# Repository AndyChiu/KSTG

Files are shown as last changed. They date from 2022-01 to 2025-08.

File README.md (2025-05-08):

# KSTG
鍵帽存放托盤產生器(Keycap Storage Tray Generator)
Version: 2025/5/8

此產生器使用OpenSCAD來打造存放鍵帽的托盤，可以有效運用廢棄盒子，依盒子尺寸與鍵帽尺寸來建立最合適的托盤，讓空間有效運用，並減少廢棄物。\
This generator uses OpenSCAD to design trays for storing keycaps. It allows you to reuse discarded boxes efficiently by creating a tray that fits both the box and keycap dimensions, optimizing space usage and reducing waste.

範例：分隔版樣式\
Examples: Separator Styles

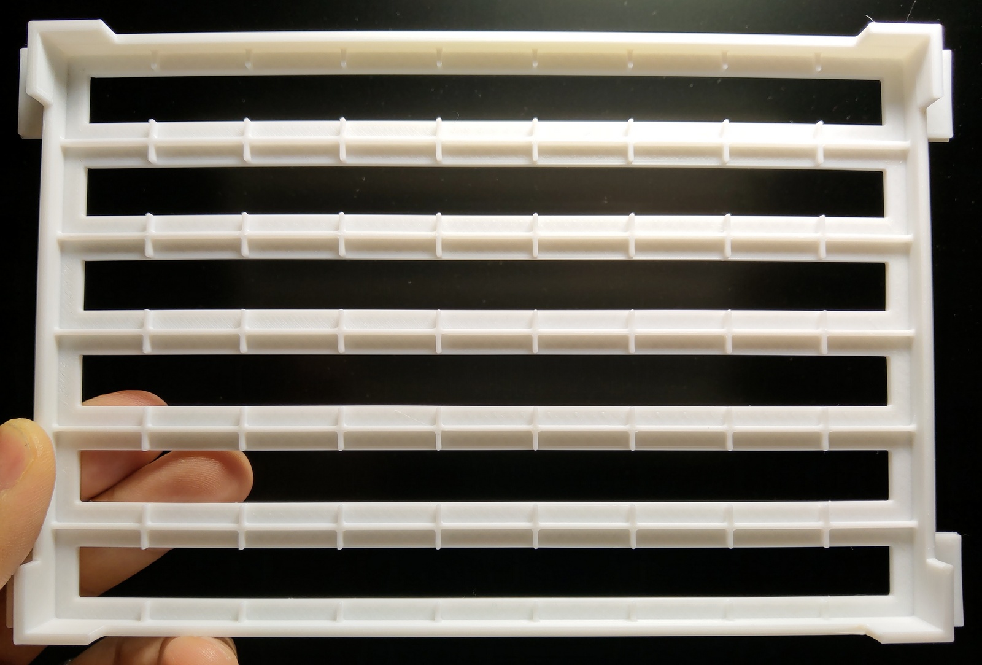
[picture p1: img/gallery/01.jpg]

垂直分隔片樣式：2-短隔板無底板\
Vertical separator style: 2 - Short dividers without base

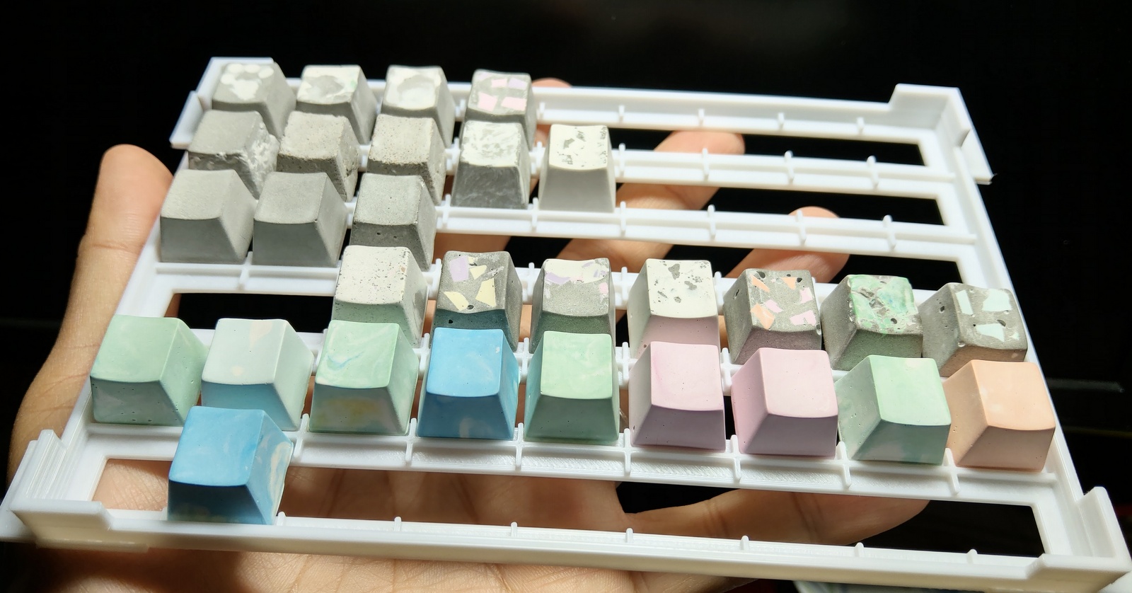
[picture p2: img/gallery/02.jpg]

垂直分隔片樣式：2-短隔板無底板\
Vertical separator style: 2 - Short dividers without base

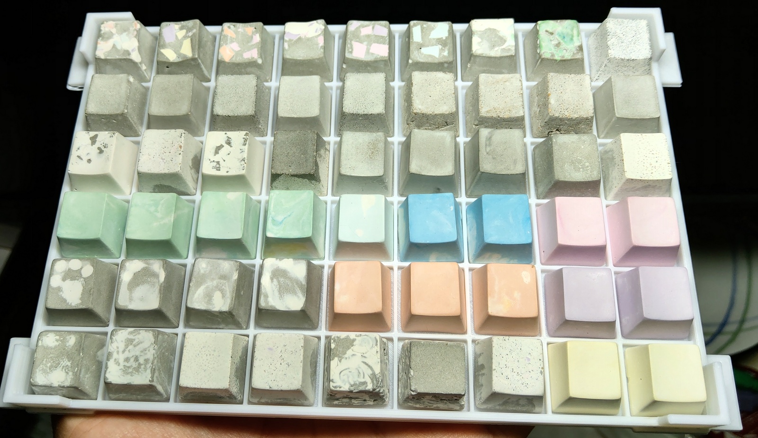
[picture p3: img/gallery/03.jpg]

垂直分隔片樣式：1-全部\
Vertical separator style: 1 - Full

範例：放入盒內\
Examples: Inside the Box

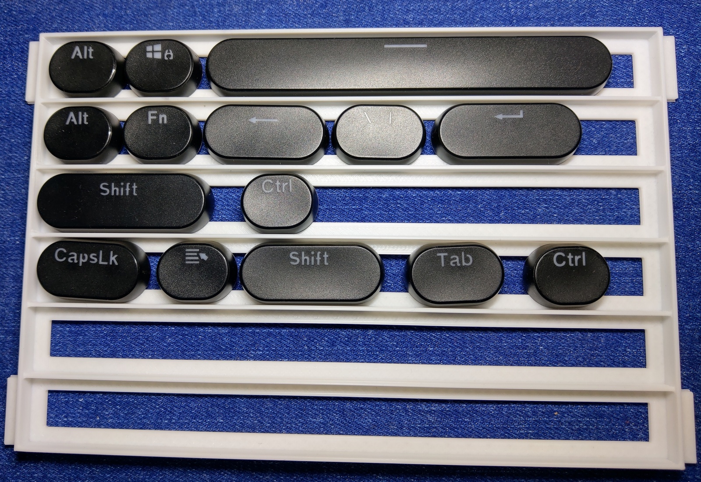
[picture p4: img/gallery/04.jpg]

垂直分隔片樣式：0-不需要\
Vertical separator style: 0 - Not needed

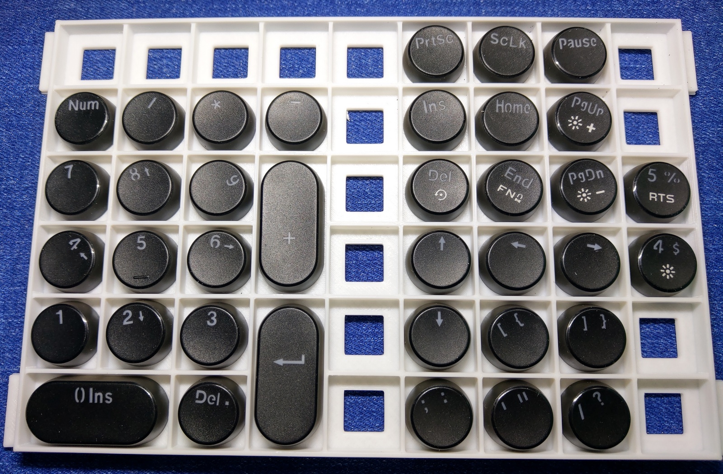
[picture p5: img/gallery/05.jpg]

垂直分隔片樣式：1-全部\
Vertical separator style: 1 - Full\
搭配手動清除分隔片與底板\
Used with manually removed separators and base plates

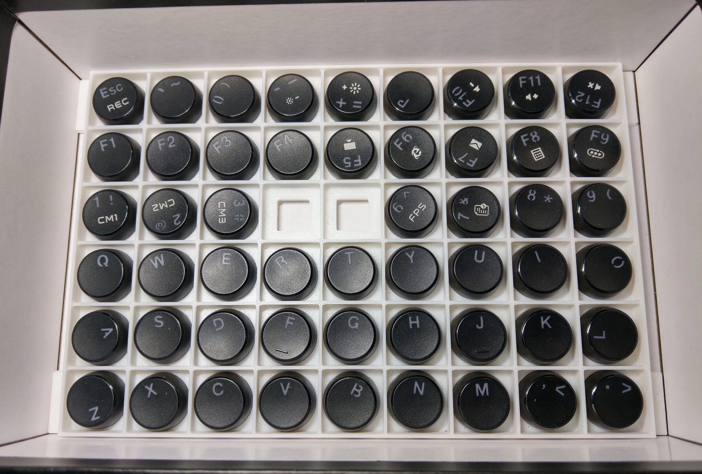
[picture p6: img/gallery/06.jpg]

放置時可預留空間，比較好拿取托盤\
Leave some space when placing to make trays easier to retrieve

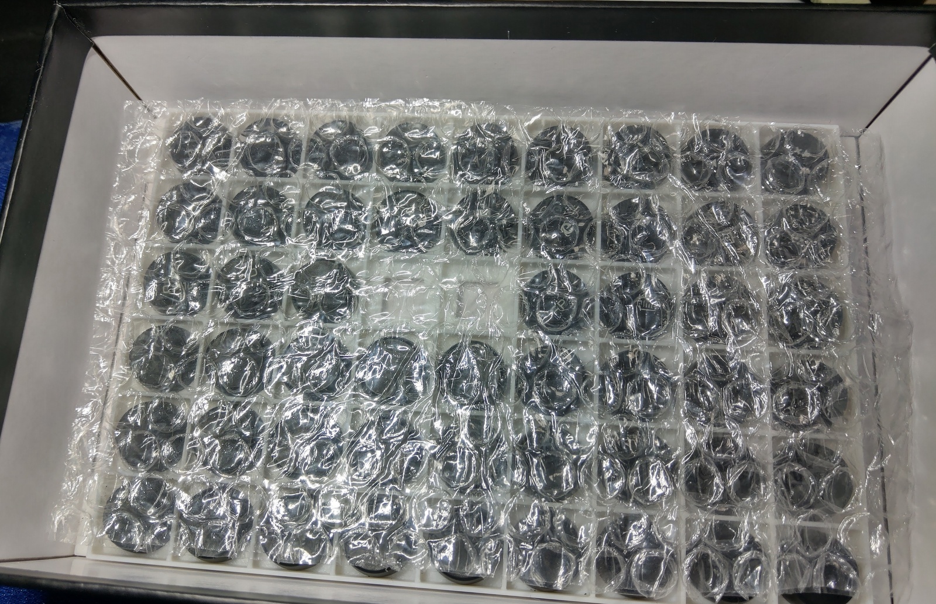
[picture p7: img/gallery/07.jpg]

裁切同等大小的泡綿\
Cut foam sheets to matching size

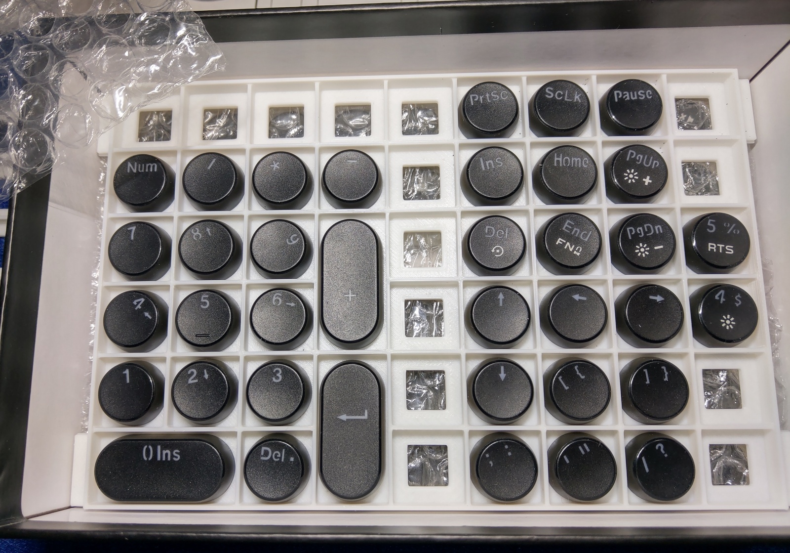
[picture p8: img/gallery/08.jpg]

再放上另一層\
Add another layer on top

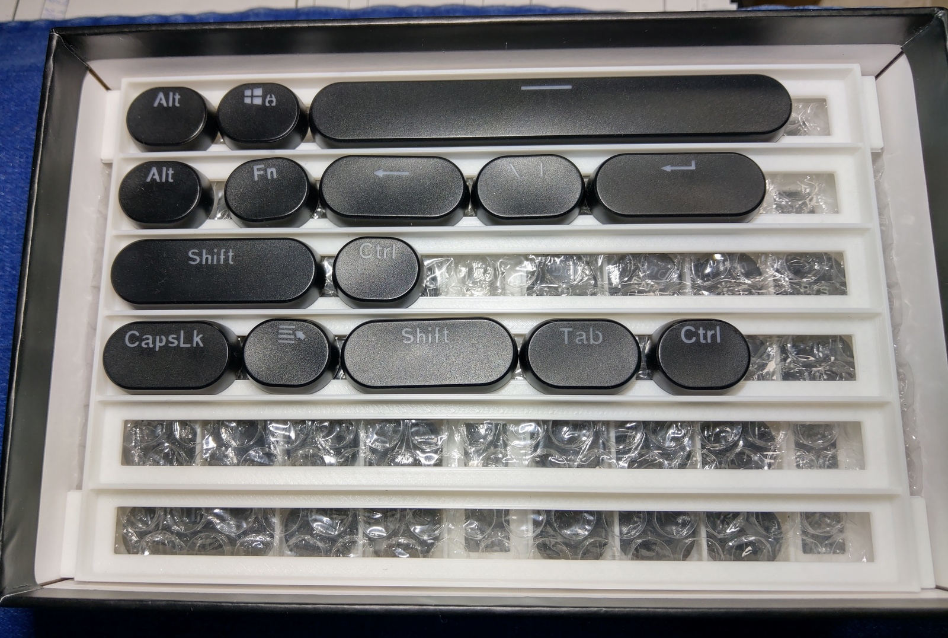
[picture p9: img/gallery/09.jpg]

放入第三層，如果空間沒有滿，可塞填充物，避免攜帶時鍵帽脫離位置\
Insert a third layer. If there’s extra space, fill with cushioning material to prevent keycaps from shifting during transport

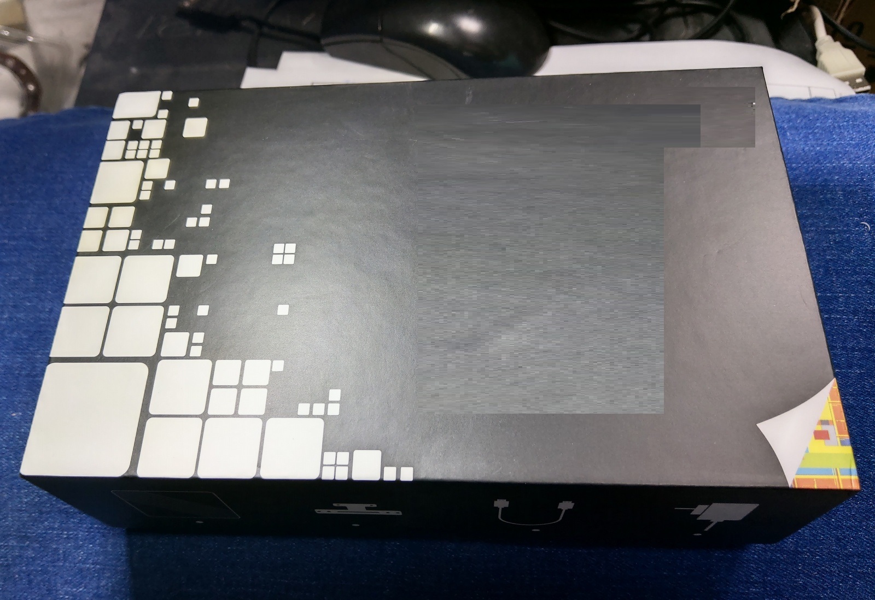
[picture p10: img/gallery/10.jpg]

蓋上盒蓋，完成收納\
Close the lid — storage complete

範例：使用B5文件夾\
Example: Using a B5 Document Folder

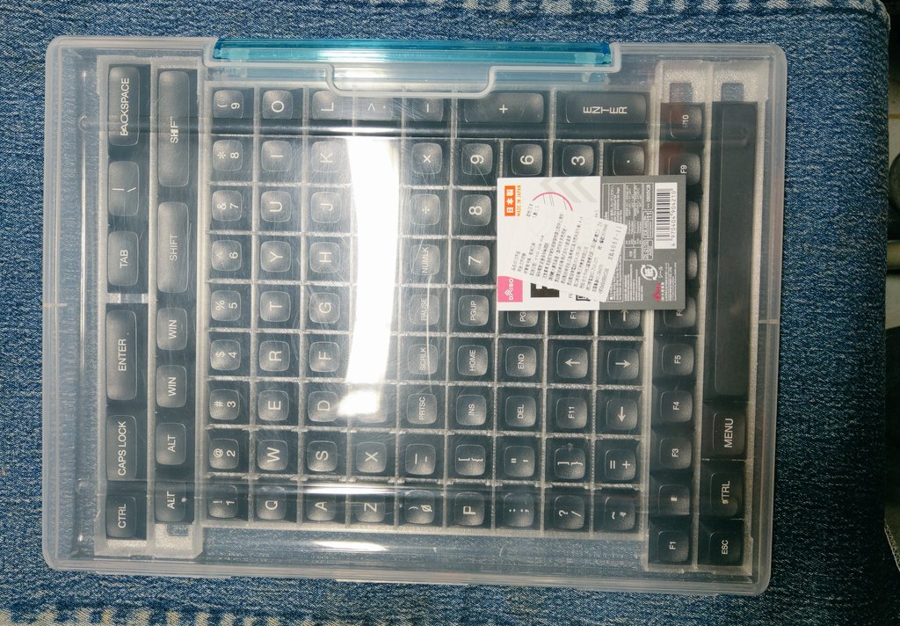
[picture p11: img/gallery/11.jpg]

B5文件夾\
B5 Document Folder

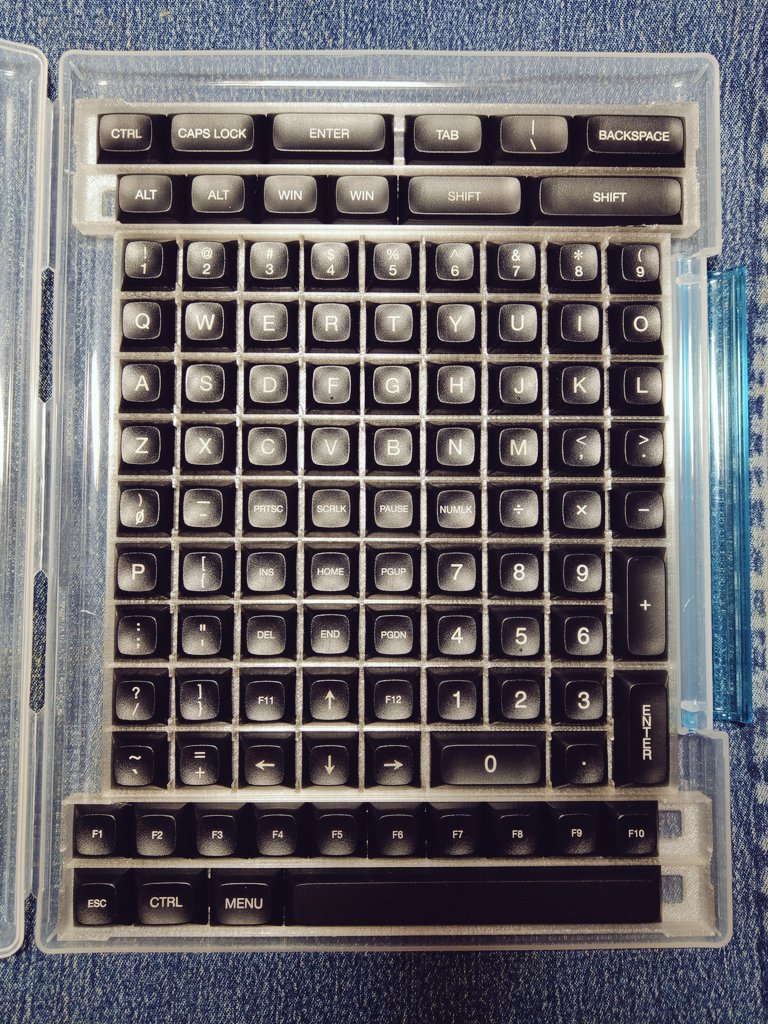
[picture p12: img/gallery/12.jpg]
\
可完整放入104鍵鍵帽\
Fits all 104 keycaps perfectly

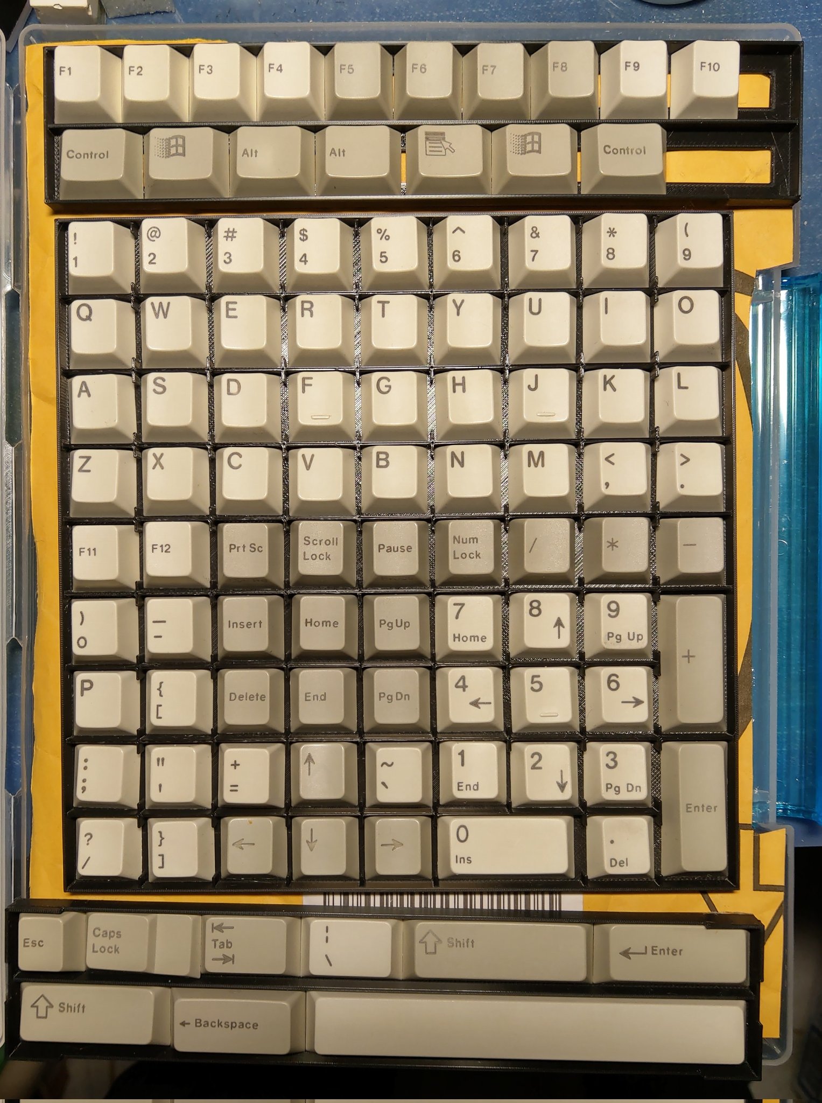
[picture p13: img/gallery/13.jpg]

第二層\
Second layer

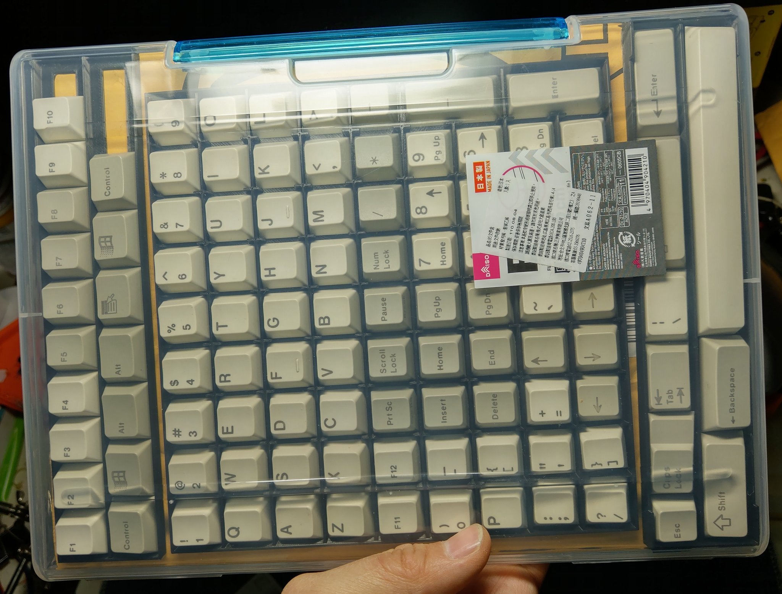
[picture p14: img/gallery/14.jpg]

兩層鍵帽組合起來高度剛好\
The height of two keycap layers fits just right

新增項目:\
New Features:

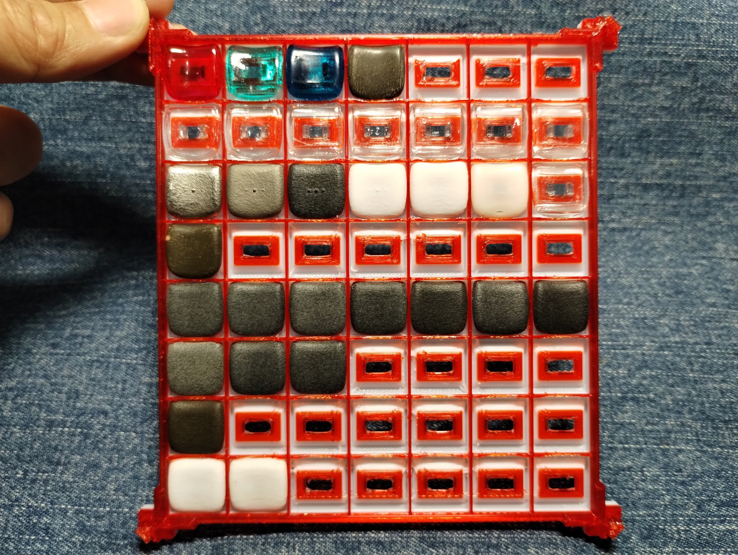
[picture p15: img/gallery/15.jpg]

Choc V1用的Stem插孔\
Stem socket for Choc V1

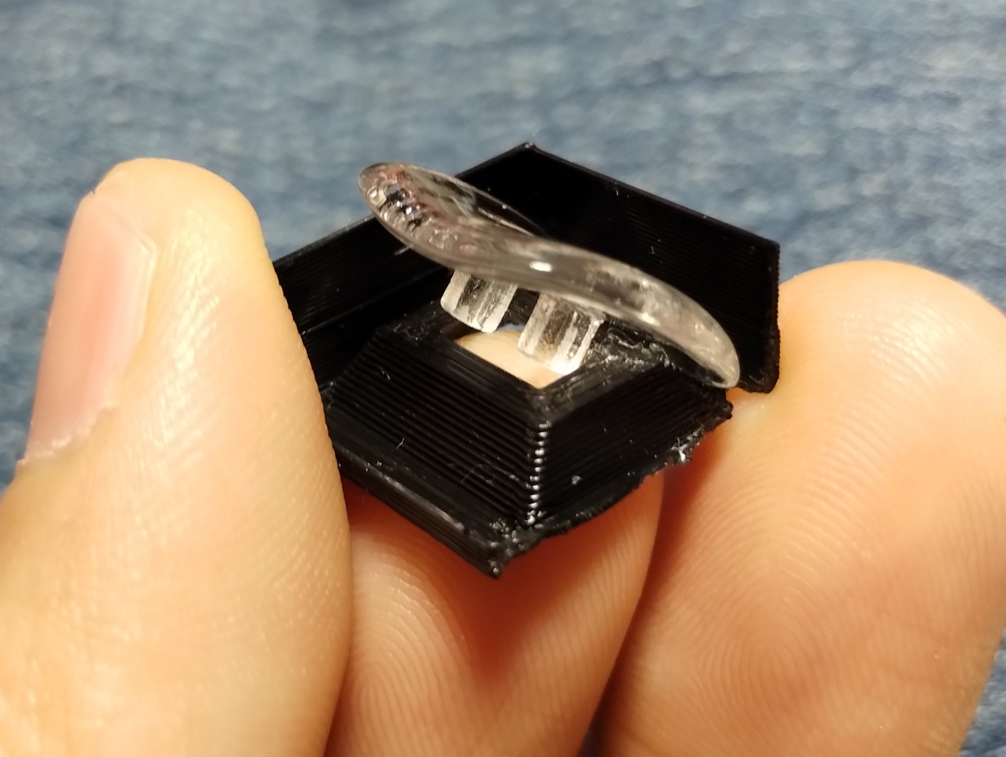
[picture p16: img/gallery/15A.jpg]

背後有往上凸，可用手指將鍵帽推出來。\
Raised backing allows keycaps to be pushed out with a finger.

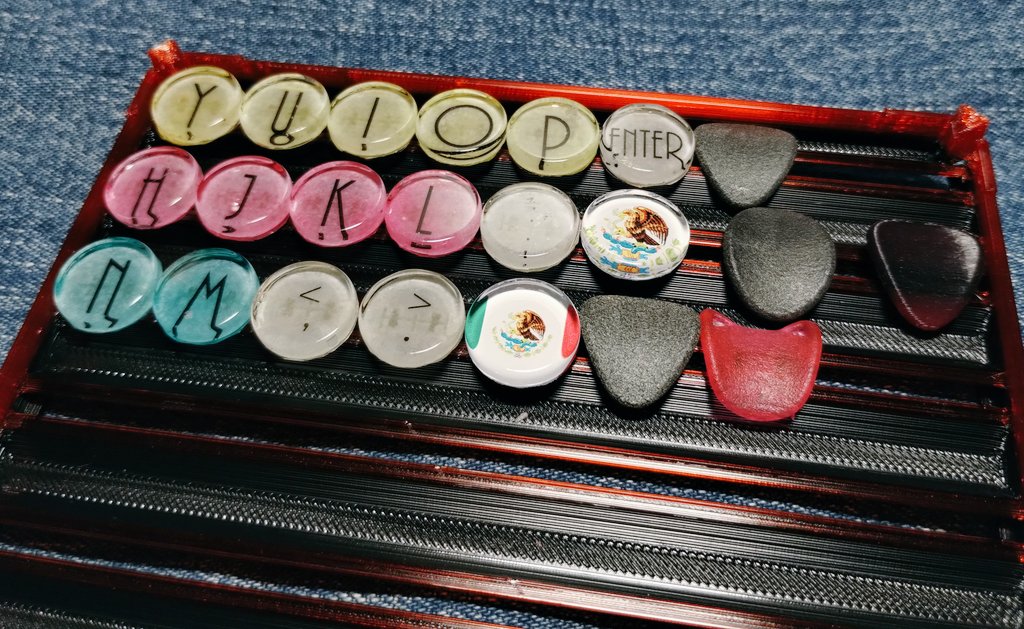
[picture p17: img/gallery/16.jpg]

Choc V1用的Stem插孔，一長排的開孔，用於無裙鍵帽，可減少部分使用空間。\
Choc V1 stem socket – a long slot designed for skirtless keycaps, saves some space.

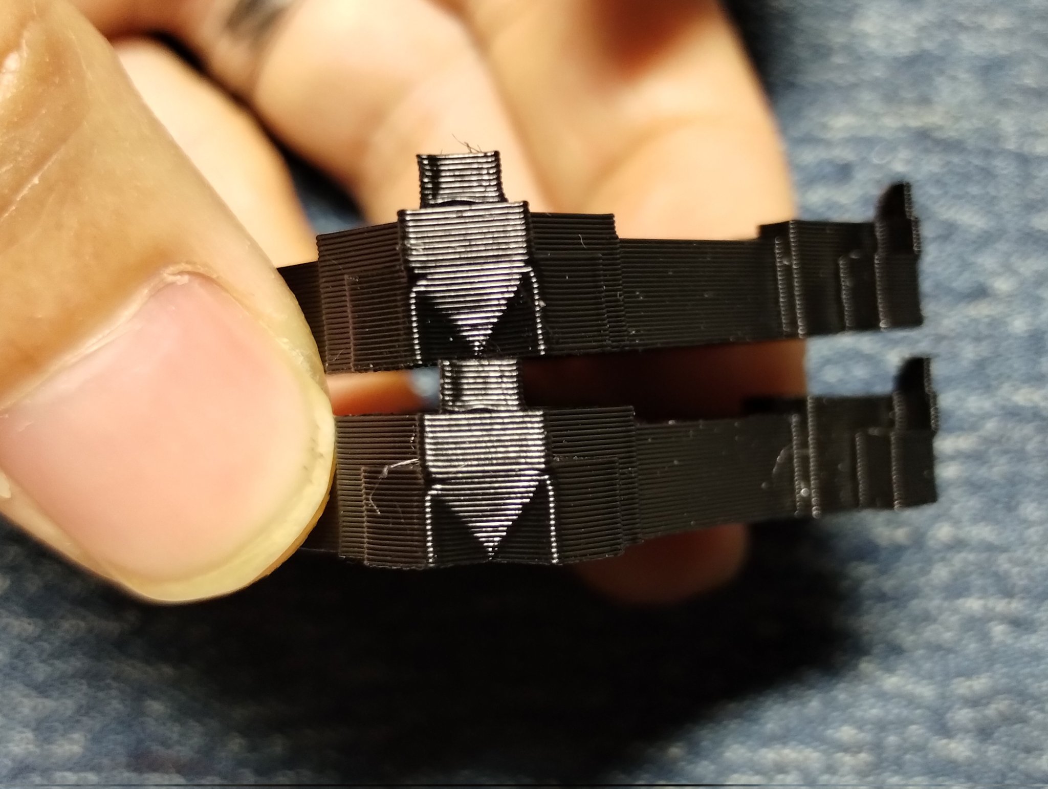
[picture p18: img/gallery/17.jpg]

托盤固定槽榫，多盤時，可以對準堆疊托盤。\
Tray alignment notches – help align and stack multiple trays.

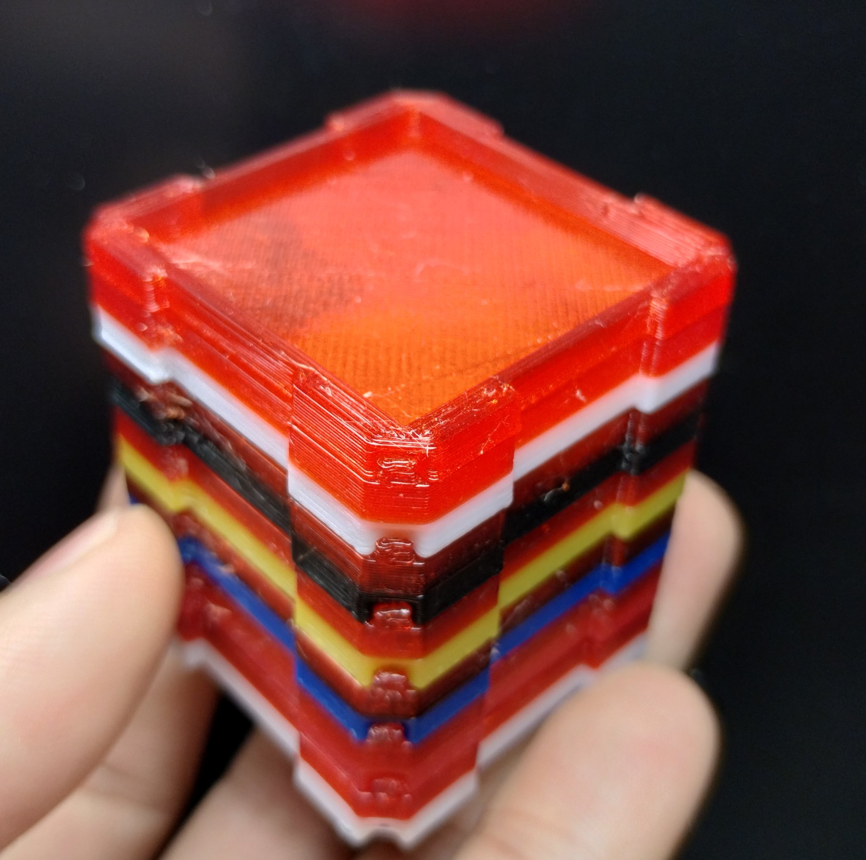
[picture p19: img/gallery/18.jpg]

多盤堆疊範例，可透過固定槽榫固定多個托盤，可由 CreateKST_Cover() 建立上蓋，如果不放盒子內，僅印出堆疊，可以用盒子蓋住，較為完整。\
Example of stacking multiple trays: alignment notches allow trays to be securely stacked. A top cover can be created using CreateKST_Cover(). If not placing the trays inside a box, simply printing and covering the stack with a lid provides a more complete solution.

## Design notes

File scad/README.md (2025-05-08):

# 主程式 Main Program
請複製一份 KSTG_Template.scad 檔案，並依照自己的情況修改參數，再自行改成所需的檔案名稱即可
此檔案會載入 KSTG_Base.SCAD，只要這個檔案不改檔名，能夠被載入就沒太大的問題

Make a copy of the KSTG_Template.scad file, modify the parameters to suit your needs, and rename it as desired.
This file will load KSTG_Base.SCAD; as long as the filename remains unchanged and it can be found, everything should work fine.

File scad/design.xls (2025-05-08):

 |  |  | // 分隔片
 |  |  | Tray_Separator_L = 3; //短隔板長度
 |  |  | // 分隔片(長寬區分)
 |  |  | Tray_Separator_H_L = 4; //高度(長;水平)
 |  |  | Tray_Separator_T_L = 1; //厚度(長;水平)
 |  |  | Tray_Separator_H_W = 4; //高度(寬;垂直)
 |  |  | Tray_Separator_T_W = 2; //厚度(寬;垂直)
 |  |  | //四角落立柱高度
 |  |  | //堆疊托盤時可墊高避免直接碰觸鍵帽
 |  |  | Tray_Column_H = 10; // 高度 可依照鍵帽高度調整
 |  |  | Tray_Column_T = 2; // 厚度
 |  | //填補空間高度 | Tray_Column_W = 15; // 寬面長度
// 外圍厚度 | Tray_Column_L = 15; | ES_H = 3;
Tray_Fence_T = 1; //厚度 | // 長面長度
Tray_Fence_H = 4; //高度 |  | //延伸長度
 |  | ES_WE = 10;
 |  | ES_LE = 10;
 |  |  | // 底板
 | //放置鍵帽空間 |  | // 如果給Stem突出的鍵帽,計算出的"中央開口"孔徑要大於特定尺寸才能正常插入,厚度值則要足夠才不會接觸到下層鍵帽,例如iRock矮鍵帽需5.5mm厚度3.5mm、Kailh Choc矮軸鍵帽需7mm厚度2mm,如開口不夠大請調整 Tray_Bottom_L 參數
 | Keycaps_Space_L = 20.6; |  | Tray_Bottom_L = (Keycaps_Space_W-9)/2; //水平底板寬度
 | Keycaps_Space_W = 16.6; |  | Tray_Bottom_W = (Keycaps_Space_L-14)/2; //垂直底板寬度
 |  |  | Tray_Bottom_T = 2; //底板厚度
 |  |  | Tray_Corner_FST_HA = 0; // 高度增減，可依需求調整 // Height adjustment – customize as needed
 |  |  | Tray_Corner_FST_D = 45; // 斜切角度 // Chamfer angle
 |  |  | Tray_Corner_FST_L = 5; // 長面長度 // Long side length
 |  |  | Tray_Corner_FST_W = 5; // 寬面長度，長寬建議相同 // Wide side length (suggest keeping width = length)
 |  |  | Tray_Corner_FST_S = 0.4; // 榫縮尺寸 // Tenon shrink offset
 |  |  | Tray_Corner_FST_TH = 3; // 榫頭高度 // Tenon head height
 |  |  | // 存放盒子的大小:
 |  |  | BoxSize_L1 = 137; //Length 長度(水平;x軸) row
 |  |  | BoxSize_W1 = 147; //Width 寬度(垂直;y軸) col
 |  |  | BoxSize_H1 = 49.5; //Height 高度
 |  |  | //水平分隔片 行數 (長;水平)
 |  |  | //=((外盒寬度 - (外圍厚度*2) + 邊緣分隔板厚度 )
 |  |  | // /(放置鍵帽空間W+分隔片L厚度))
 |  |  | Tray_HS_Q = floor((BoxSize_W1-(Tray_Fence_T*2)+Edge_Separator_L_T)/(Keycaps_Space_W+Tray_Separator_T_L));

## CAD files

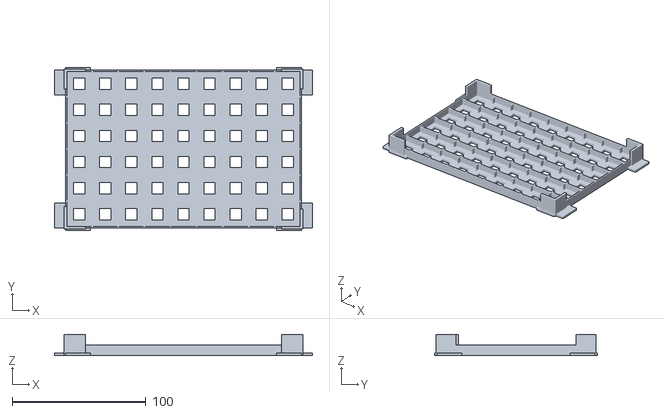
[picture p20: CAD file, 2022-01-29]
stl_Sample/KSTG_Sample5.stl
193.0 x 122.0 x 16.0

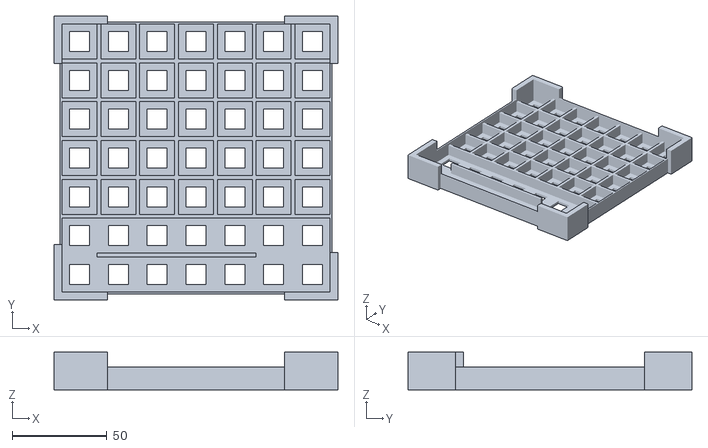
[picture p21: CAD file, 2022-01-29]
stl_Sample/KSTG_Sample7.stl
150.0 x 150.0 x 20.0

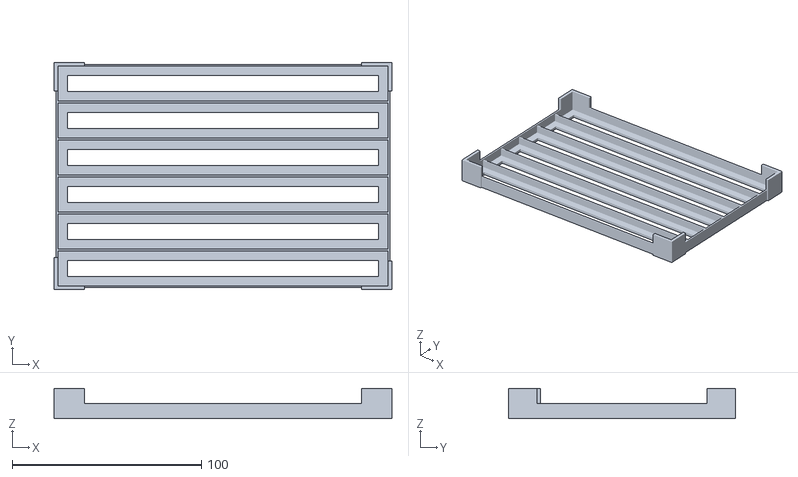
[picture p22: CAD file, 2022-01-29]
stl_Sample/KSTG_Sample4.stl
178.5 x 120.0 x 16.0

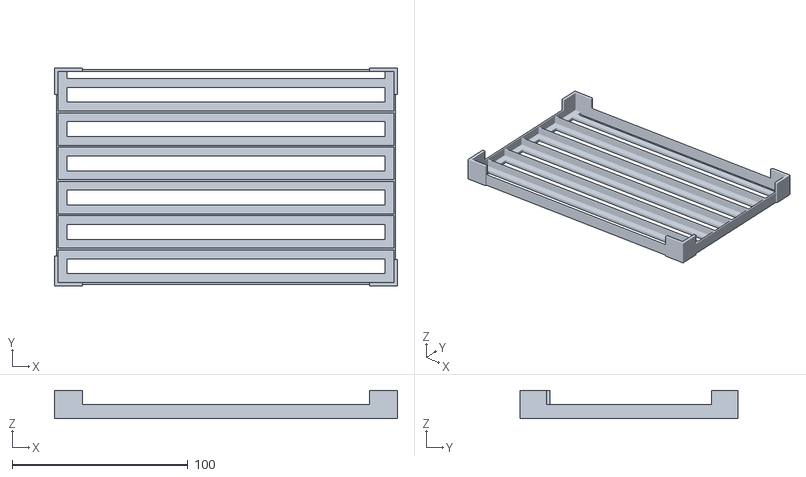
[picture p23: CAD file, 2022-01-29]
stl_Sample/KSTG_Sample3.stl
195.0 x 124.0 x 16.0

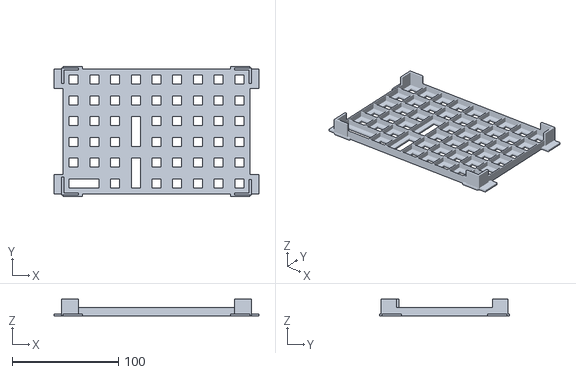
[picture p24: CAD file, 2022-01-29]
stl_Sample/KSTG_Sample1.stl
193.0 x 122.0 x 16.0

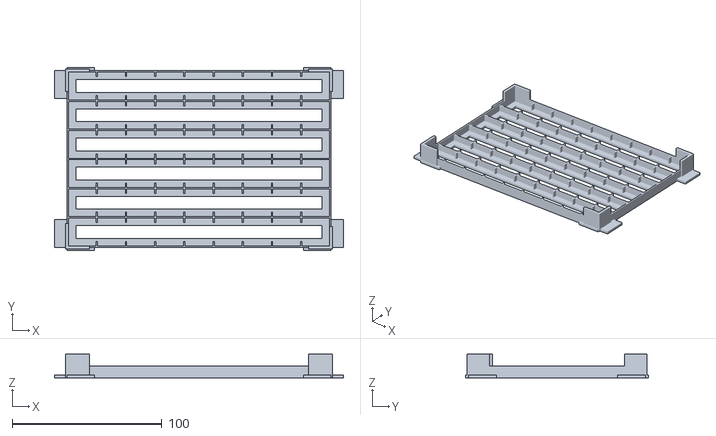
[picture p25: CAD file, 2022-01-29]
stl_Sample/KSTG_Sample6.stl
193.0 x 122.0 x 16.0

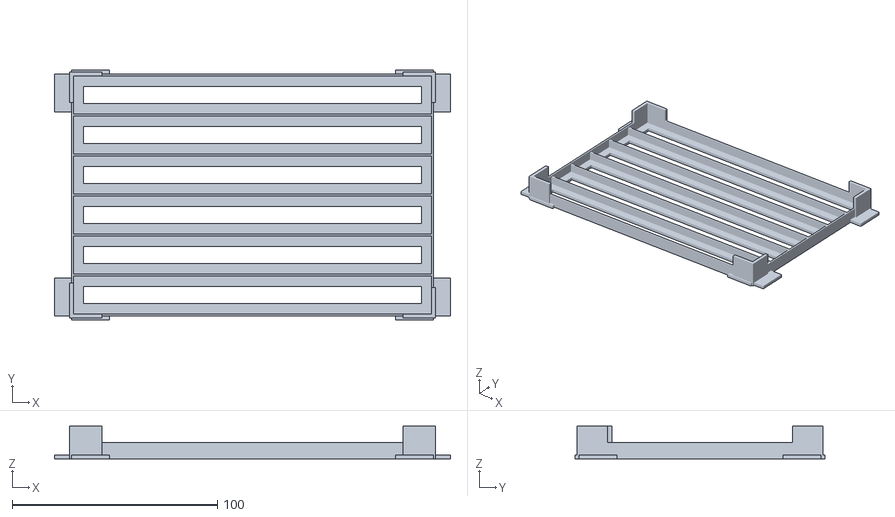
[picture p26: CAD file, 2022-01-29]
stl_Sample/KSTG_Sample2.stl
193.0 x 122.0 x 16.0

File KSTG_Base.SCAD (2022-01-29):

// Keycaps 存放架產生器
// keycap storage tray generator

module CreateBase() 
{
//邊緣分隔板厚度(最小值)
Edge_Separator_L_T = Tray_Fence_T > Tray_Separator_T ?  Tray_Separator_T : Tray_Fence_T ;
Edge_Separator_W_T= Tray_Fence_T > Tray_Separator_T ? Tray_Fence_T : Tray_Separator_T ;
    
//水平分隔片 行數 長度(水平)
Tray_HS_Q = floor((BoxSize_W1-(Tray_Fence_T*2)+Edge_Separator_L_T)/(Keycaps_Space_W+Tray_Separator_T));

//垂直分隔片 列數 寬度(垂直)
Tray_VS_Q = floor((BoxSize_L1-(Tray_Fence_T*2)+Edge_Separator_W_T)/(Keycaps_Space_L+Tray_Separator_T));

//盒子可放幾個托盤
Tray_Q = floor(BoxSize_H/(Tray_Column_H+Tray_Bottom_T));

echo(str("存放盒子長寬高：", BoxSize_L1,"mm x ",BoxSize_W1,"mm x ",BoxSize_H, "mm"));

echo(str("托盤分隔 行x列 數：", Tray_HS_Q,"行 x ",Tray_VS_Q,"列"));

//可使用總U數
echo(str("單一托盤可裝：", Tray_HS_Q*Tray_VS_Q, "U"));
echo(str("單盒可存盤數：", Tray_Q, ""));
echo(str("單盒可存鍵帽：", Tray_HS_Q*Tray_VS_Q*Tray_Q, "U"));

// 修正後存放盒子的大小:
BoxSize_L2 = Tray_VS_Q*(Keycaps_Space_L+Tray_Separator_T)+(Tray_Fence_T*2)-Tray_Separator_T; //長度
BoxSize_W2 = Tray_HS_Q*(Keycaps_Space_W+Tray_Separator_T)+(Tray_Fence_T*2)-Tray_Separator_T; //寬度
echo("使用空間L2=", BoxSize_L2, "");
echo("使用空間W2=", BoxSize_W2, "");

//多出來的邊界空間
ES_L2=BoxSize_L1-BoxSize_L2;
ES_W2=BoxSize_W1-BoxSize_W2;

ES_L=ES_L2/2;
ES_W=ES_W2/2;

echo("多餘空間L=", ES_L2, "");
echo("多餘空間W=", ES_W2, "");

echo("中央開口",Keycaps_Space_L-(Tray_Bottom_L*2)," x ",Keycaps_Space_W-(Tray_Bottom_L*2));

BoxSize_L = ExtraSpaceUse==0 ? BoxSize_L1 : BoxSize_L2;
BoxSize_W = ExtraSpaceUse==0 ? BoxSize_W1 : BoxSize_W2;

//繪製四面牆
cube([BoxSize_L,Tray_Fence_T,Tray_Fence_H+Tray_Bottom_T],false); //長 水平
cube([Tray_Fence_T,BoxSize_W,Tray_Fence_H+Tray_Bottom_T],false); //寬 垂直
translate([0,BoxSize_W-Tray_Fence_T,0]) 
    cube([BoxSize_L,Tray_Fence_T,Tray_Fence_H+Tray_Bottom_T],false);
translate([BoxSize_L-Tray_Fence_T,0,0]) 
    cube([Tray_Fence_T,BoxSize_W,Tray_Fence_H+Tray_Bottom_T],false);
//長 水平 底板    
//translate([0,Tray_Fence_T,0]) 
//    cube([BoxSize_L,Tray_Bottom_L+Tray_Separator_T/2,Tray_Bottom_T],false);
//translate([0,BoxSize_W-Tray_Fence_T-Tray_Bottom_L,0]) 
//    cube([BoxSize_L,Tray_Bottom_L,Tray_Bottom_T],false);
    
//寬 垂直 底板    
translate([0,0,0]) 
    cube([Tray_Fence_T+Tray_Bottom_L,BoxSize_W,Tray_Bottom_T],false);
translate([BoxSize_L-(Tray_Fence_T+Tray_Bottom_L),0,0]) 
    cube([Tray_Fence_T+Tray_Bottom_L,BoxSize_W,Tray_Bottom_T],false);

//水平搭橋 四面牆不處理   

//底板
for (i =[1:Tray_HS_Q])
translate([0,(Keycaps_Space_L+Tray_Separator_T)*i-Tray_Bottom_L+Tray_Fence_T-Tray_Separator_T,0]) 
    cube([BoxSize_L,Tray_Bottom_L,Tray_Bottom_T],false);

for (i =[1:Tray_HS_Q])
translate([0,(Keycaps_Space_L+Tray_Separator_T)*(i-1)+Tray_Fence_T,0]) 
    cube([BoxSize_L,Tray_Bottom_L,Tray_Bottom_T],false);

//水平分隔片 
//abs(Tray_Fence_T-Tray_Separator_T)
for (i =[1:Tray_HS_Q-1])
translate([0,(Keycaps_Space_L+Tray_Separator_T)*i+Tray_Fence_T-Tray_Separator_T,0]) 
    cube([BoxSize_L,Tray_Separator_T,Tray_Separator_H+Tray_Bottom_T],false);
    
//垂直搭橋

// 0 不使用
//if(Tray_VS_Type==0);

// 1、3 底板
if(Tray_VS_Type==1 || Tray_VS_Type==3) {
    //右
    for (i =[1:Tray_VS_Q])
    translate([(Keycaps_Space_W+Tray_Separator_T)*i-Tray_Bottom_L-Tray_Separator_T+Tray_Fence_T,0,0]) 
        cube([Tray_Bottom_L,BoxSize_W,Tray_Bottom_T],false);
    //左
    for (i =[1:Tray_VS_Q-1])
    translate([(Keycaps_Space_W+Tray_Separator_T)*i+Tray_Fence_T,0,0]) 
        cube([Tray_Bottom_L,BoxSize_W,Tray_Bottom_T],false);
    //中
    for (i =[1:Tray_VS_Q-1])
    translate([(Keycaps_Space_W+Tray_Separator_T)*i-Tray_Separator_T+Tray_Fence_T,0,0])  
        cube([Tray_Separator_T,BoxSize_W,Tray_Bottom_T],false);
    }

// 垂直分隔片  
// 2、3 短隔板
if(Tray_VS_Type==2 || Tray_VS_Type==3) {
      
    //上
    for (i =[1:Tray_VS_Q-1])
        for (j =[1:Tray_HS_Q])
    translate([(Keycaps_Space_W+Tray_Separator_T)*i+Tray_Fence_T-Tray_Separator_T,(Keycaps_Space_L+Tray_Separator_T)*j-Tray_Separator_L+Tray_Fence_T-Tray_Separator_T,0]) 
        cube([Tray_Separator_T,Tray_Separator_L,Tray_Separator_H+Tray_Bottom_T],false);
    //下
    for (i =[1:Tray_VS_Q-1])
        for (j =[1:Tray_HS_Q])
    translate([(Keycaps_Space_W+Tray_Separator_T)*i+Tray_Fence_T-Tray_Separator_T,(Keycaps_Space_L+Tray_Separator_T)*(j-1)+Tray_Fence_T,0]) 
        cube([Tray_Separator_T,Tray_Separator_L,Tray_Separator_H+Tray_Bottom_T],false);

    }
// 2 全部
else if(Tray_VS_Type==1) {
    //垂直分隔片    
    for (i =[1:Tray_VS_Q-1])
    translate([(Keycaps_Space_W+Tray_Separator_T)*i+Tray_Fence_T-Tray_Separator_T,0,0]) 
        cube([Tray_Separator_T,BoxSize_W,Tray_Separator_H+Tray_Bottom_T],false);
    
    }
 
//多餘空間處理方式
// 2 角落填補剩餘空間
 if (ExtraSpaceUse == 2) {
    //左下下
    translate([0,-ES_W,0]) 
        cube([Keycaps_Space_W,ES_W,Tray_Bottom_T],false);
    //左下左
     translate([-ES_L,0,0]) 
        cube([ES_L,Keycaps_Space_L,Tray_Bottom_T],false);    

     //左上左
     translate([-ES_L,BoxSize_W-Keycaps_Space_L,0]) 
        cube([ES_L,Keycaps_Space_L,Tray_Bottom_T],false); 
     //左上上
     translate([0,BoxSize_W,0]) 
        cube([Keycaps_Space_W,ES_W,Tray_Bottom_T],false);
     //右下右
     translate([BoxSize_L,0,0]) 
        cube([ES_L,Keycaps_Space_L,Tray_Bottom_T],false);    
     //右下下
     translate([BoxSize_L-Keycaps_Space_W,-ES_W,0]) 
        cube([Keycaps_Space_W,ES_W,Tray_Bottom_T],false);
     //右上右
     translate([BoxSize_L,BoxSize_W-Keycaps_Space_L,0]) 
        cube([ES_L,Keycaps_Space_L,Tray_Bottom_T],false);    
     //右上上
     translate([BoxSize_L-Keycaps_Space_W,BoxSize_W,0]) 
        cube([Keycaps_Space_W,ES_W,Tray_Bottom_T],false);
        
    }
     
// 四角落立柱
  
Tray_Column_T_L = Tray_Column_T > Tray_Fence_T + ES_L ?  Tray_Fence_T + ES_L : Tray_Column_T ;

Tray_Column_T_W = Tray_Column_T > Tray_Fence_T + ES_W ?  Tray_Fence_T + ES_W : Tray_Column_T ;

// 左下下
translate([0,Tray_Fence_T-Tray_Column_T_W,0]) 
    cube([Tray_Column_L,Tray_Column_T_W,Tray_Column_H+Tray_Bottom_T],false);  
// 左下左
translate([Tray_Fence_T-Tray_Column_T_L,Tray_Fence_T-Tray_Column_T_W,0]) 
    cube([Tray_Column_T_L,Tray_Column_L+Tray_Column_T_L,Tray_Column_H+Tray_Bottom_T],false);   
// 右下下
translate([BoxSize_L-Tray_Column_L,Tray_Fence_T-Tray_Column_T_W,0]) 
    cube([Tray_Column_L,Tray_Column_T_W,Tray_Column_H+Tray_Bottom_T],false);
// 右下右
translate([BoxSize_L-Tray_Column_T_L-Tray_Fence_T+Tray_Column_T_W,Tray_Fence_T-Tray_Column_T_L,0]) 
    cube([Tray_Column_T_L,Tray_Column_W,Tray_Column_H+Tray_Bottom_T],false); 
// 左上上     
translate([0,BoxSize_W-Tray_Column_T_W-Tray_Fence_T+Tray_Column_T_W,0]) 
    cube([Tray_Column_L,Tray_Column_T_W,Tray_Column_H+Tray_Bottom_T],false);
// 左上左   
translate([Tray_Fence_T-Tray_Column_T_L,BoxSize_W-Tray_Column_W-Tray_Fence_T+Tray_Column_T_W,0])
    cube([Tray_Column_T_L,Tray_Column_W,Tray_Column_H+Tray_Bottom_T],false); 
//右上上
translate([BoxSize_L-Tray_Column_L,BoxSize_W-Tray_Column_T_W-Tray_Fence_T+Tray_Column_T_W,0]) 
    cube([Tray_Column_L,Tray_Column_T_W,Tray_Column_H+Tray_Bottom_T],false);
//右上右   
translate([BoxSize_L-Tray_Column_T_L-Tray_Fence_T+Tray_Column_T_L,BoxSize_W-Tray_Column_W-Tray_Fence_T+Tray_Column_T_W,0])
    cube([Tray_Column_T_L,Tray_Column_W,Tray_Column_H+Tray_Bottom_T],false); 

//文字標記
if (ShowText==1) { 
    
for (i =[1:Tray_VS_Q])
    for (j =[1:Tray_HS_Q-1])
    translate([(Keycaps_Space_W+Tray_Separator_T)*i+Tray_Fence_T-Tray_Separator_T-Keycaps_Space_W/1.5,(Keycaps_Space_L+Tray_Separator_T)*j-Tray_Bottom_L+Tray_Fence_T-Tray_Separator_T+3,Tray_Bottom_T+Tray_Separator_H+1]) 
        color( "Red", 0.3 )text(str(i,",",j),3);

for (i =[1:Tray_VS_Q-1])
    for (j =[1:Tray_HS_Q])
    translate([(Keycaps_Space_W+Tray_Separator_T)*i+Tray_Fence_T-Tray_Separator_T-Keycaps_Space_W/4+3,(Keycaps_Space_L+Tray_Separator_T)*j-Tray_Bottom_L+Tray_Fence_T-Tray_Separator_T-Keycaps_Space_L/2+3,Tray_Bottom_T+Tray_Separator_H+1]) 
        color( "Navy", 0.3 )text(str(i,",",j),3);

for (i =[1:Tray_VS_Q-1])
    for (j =[1:Tray_HS_Q-1])
    translate([(Keycaps_Space_W+Tray_Separator_T)*i+Tray_Fence_T-Tray_Separator_T-Keycaps_Space_W/4+3,(Keycaps_Space_L+Tray_Separator_T)*j-Tray_Bottom_L+Tray_Fence_T-Tray_Separator_T+3,Tray_Bottom_T+Tray_Separator_H+1]) 
        color( "Lime", 0.3 )text(str(i,",",j),3);
    
};

}
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

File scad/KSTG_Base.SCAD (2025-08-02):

/*
====================================
  鍵帽存放托盤產生器(KSTG)
  Keycap Storage Tray Generator
====================================
使用 include <KSTG_Base.SCAD> 加載此檔案
Use include <KSTG_Base.SCAD> to load this file

建立鍵帽存放托盤
Create Keycap Storage Tray
CreateKST();

建立鍵帽存放托盤上蓋
Create Keycap Storage Tray Cover
CreateKST_Cover();

KSTG_Template.scad 有詳細設定說明
KSTG_Template.scad contains detailed configuration instructions
*/

module CreateBase() 
{
//邊緣分隔板厚度(分隔片厚度 與 外圍厚度 取最小值)
Edge_Separator_L_T = Tray_Fence_T > Tray_Separator_T_L ?  Tray_Separator_T_L : Tray_Fence_T ;
Edge_Separator_W_T= Tray_Fence_T > Tray_Separator_T_W ? Tray_Fence_T : Tray_Separator_T_W ;
    
//水平分隔片 行數 (長;水平)
//=((外盒寬度 - (外圍厚度*2) + 邊緣分隔板厚度L )
//  /(放置鍵帽空間W+分隔片L厚度))

Tray_HS_Q = floor((BoxSize_W1-(Tray_Fence_T*2)+Edge_Separator_L_T)/(Keycaps_Space_W+Tray_Separator_T_L));

//垂直分隔片 列數 (寬;垂直)
//=((外盒長度 - (外圍厚度*2) + 邊緣分隔板厚度W )
//  /(放置鍵帽空間L+分隔片W厚度))

Tray_VS_Q = floor((BoxSize_L1-(Tray_Fence_T*2)+Edge_Separator_W_T)/(Keycaps_Space_L+Tray_Separator_T_W));

//盒子可放幾個托盤
Tray_Q = floor(BoxSize_H1/(Tray_Column_H+Tray_Bottom_T));

echo(str("存放盒子長寬高：", BoxSize_L1," x ",BoxSize_W1," x ",BoxSize_H1, " mm"));

echo(str("托盤分隔 行x列 數：", Tray_HS_Q,"行 x ",Tray_VS_Q,"列"));

//可使用總U數
echo(str("單一托盤可裝：", Tray_HS_Q*Tray_VS_Q, "U"));
echo(str("單盒可存盤數：", Tray_Q, "盤"));
echo(str("單盒可存鍵帽：", Tray_HS_Q*Tray_VS_Q*Tray_Q, "U"));

// 修正後存放盒子的大小:
BoxSize_L2 = Tray_VS_Q*(Keycaps_Space_L+Tray_Separator_T_W)+(Tray_Fence_T*2)-Tray_Separator_T_W; //長度
BoxSize_W2 = Tray_HS_Q*(Keycaps_Space_W+Tray_Separator_T_L)+(Tray_Fence_T*2)-Tray_Separator_T_L; //寬度
BoxSize_H2 = Tray_Q * (Tray_Column_H+Tray_Bottom_T); //高度

echo(str("使用空間L2=", BoxSize_L2, " mm"));
echo(str("使用空間W2=", BoxSize_W2, " mm"));
echo(str("使用空間H2=", BoxSize_H2, " mm"));

//多出來的邊界空間
ES_L2=BoxSize_L1-BoxSize_L2;
ES_W2=BoxSize_W1-BoxSize_W2;
ES_H2=BoxSize_H1-BoxSize_H2;

ES_L=ES_L2/2;
ES_W=ES_W2/2;

echo(str("多餘空間L(雙邊總和)=", ES_L2, " mm"));
echo(str("多餘空間W(雙邊總和)=", ES_W2, " mm"));
echo(str("多餘空間H(頂層)=", ES_H2, " mm"));
echo(str("1U存放空間：",Keycaps_Space_L," x ",Keycaps_Space_W," x ", Tray_Column_H," mm"));


echo(str("中央開口：",Keycaps_Space_W-(Tray_Bottom_W*2)," x ",Keycaps_Space_L-(Tray_Bottom_L*2)," x ",Tray_Bottom_T," mm"));

BoxSize_L = ExtraSpaceUse==0 ? BoxSize_L1 : BoxSize_L2;
BoxSize_W = ExtraSpaceUse==0 ? BoxSize_W1 : BoxSize_W2;

Tray_Corner_FST_H =
        (Tray_Corner_FST) && (Tray_Column_H>=Tray_Fence_H) && (Tray_Column_H>=ES_H) 
        ?  Tray_Column_H + Tray_Bottom_T + Tray_Corner_FST_HA
        : (Tray_Corner_FST) && (Tray_Fence_H>=Tray_Column_H) && (Tray_Fence_H>=ES_H) 
        ?  Tray_Fence_H + Tray_Bottom_T + Tray_Corner_FST_HA
        : (Tray_Corner_FST) && (ES_H>=Tray_Column_H) && (ES_H>=Tray_Fence_H) 
        ?  ES_H + Tray_Bottom_T + Tray_Corner_FST_HA 
        : 0;
        
echo(str("卡榫高度=", Tray_Corner_FST_H, " mm"));

Tray_Fence_T2 = (Tray_Corner_FST && Tray_Corner_FST_Type == 2) ? Tray_Fence_T:0;

//分隔板最高的高度
Tray_Separator_H1 =
        Tray_Separator_H_L>=Tray_Separator_H_W
        ?  Tray_Separator_H_L : Tray_Separator_H_W;

//F5預覽檢視 模擬
//顯示存放盒
if (ShowOuterrBox==true) {
    translate([-ES_L,-ES_W,0])
    %cube([BoxSize_L1,BoxSize_W1,BoxSize_H1]);
}   
//模擬塞滿托盤
if (ShowFillingUpTrays==true) {
    for (iTQ =[0 : Tray_Q-1]) {
        FirstTop_Tray= (iTQ==Tray_Q-1) ? true: false;
        translate([0,0,iTQ*Tray_Corner_FST_H])
        Tary(FirstTop_Tray);
    }
} else {
    Tary();
}        

module Tary(FirstTop_Tray=false)
{

FST_NoTenon =  (FirstTop_Tray==true) ? true : Tray_Corner_FST_NoTenon;

echo(str("省略頂端=", FST_NoTenon, ""));

difference()
{
    union()
    {

        //繪製四面牆
        cube([BoxSize_L,Tray_Fence_T,Tray_Fence_H+Tray_Bottom_T],false); //長 水平
        cube([Tray_Fence_T,BoxSize_W,Tray_Fence_H+Tray_Bottom_T],false); //寬 垂直
        translate([0,BoxSize_W-Tray_Fence_T,0]) 
            cube([BoxSize_L,Tray_Fence_T,Tray_Fence_H+Tray_Bottom_T],false);
        translate([BoxSize_L-Tray_Fence_T,0,0]) 
            cube([Tray_Fence_T,BoxSize_W,Tray_Fence_H+Tray_Bottom_T],false);
            
        //長 水平 底板    
        //translate([0,Tray_Fence_T,0]) 
        //    cube([BoxSize_L,Tray_Bottom_L+Tray_Separator_T/2,Tray_Bottom_T],false);
        //translate([0,BoxSize_W-Tray_Fence_T-Tray_Bottom_L,0]) 
        //    cube([BoxSize_L,Tray_Bottom_L,Tray_Bottom_T],false);
            
        //牆旁底板(寬;垂直)
        //左側
        translate([0,0,0]) 
            cube([Tray_Fence_T+Tray_Bottom_W,BoxSize_W,Tray_Bottom_T],false);
        //右側
        translate([BoxSize_L-(Tray_Fence_T+Tray_Bottom_W),0,0]) 
            cube([Tray_Fence_T+Tray_Bottom_W,BoxSize_W,Tray_Bottom_T],false);

        //水平搭橋 四面牆不處理   

        //底板

        //水平
        for (i =[1:Tray_HS_Q])
        translate([0,(Keycaps_Space_W+Tray_Separator_T_L)*i-Tray_Bottom_L+Tray_Fence_T-Tray_Separator_T_L,0]) 
            cube([BoxSize_L,Tray_Bottom_L,Tray_Bottom_T],false);

        for (i =[1:Tray_HS_Q])
        translate([0,(Keycaps_Space_W+Tray_Separator_T_L)*(i-1)+Tray_Fence_T,0]) 
            cube([BoxSize_L,Tray_Bottom_L,Tray_Bottom_T],false);

        //水平分隔片 
        //abs(Tray_Fence_T-Tray_Separator_T)
        for (i =[1:Tray_HS_Q-1])
        translate([0,(Keycaps_Space_W+Tray_Separator_T_L)*i+Tray_Fence_T-Tray_Separator_T_L,0]) 
            cube([BoxSize_L,Tray_Separator_T_L,Tray_Separator_H_L+Tray_Bottom_T],false);
            
        //垂直搭橋

        // 0 不使用
        //if(Tray_VS_Type==0);

        // 1、3 底板
        if(Tray_VS_Type==1 || Tray_VS_Type==3 || Tray_VS_Type==4) {
            //右
            for (i =[1:Tray_VS_Q])
            translate([(Keycaps_Space_L+Tray_Separator_T_W)*i-Tray_Bottom_W-Tray_Separator_T_W+Tray_Fence_T,0,0]) 
                cube([Tray_Bottom_W,BoxSize_W,Tray_Bottom_T],false);
            //左
            for (i =[0:Tray_VS_Q-1])
            translate([(Keycaps_Space_L+Tray_Separator_T_W)*i+Tray_Fence_T,0,0]) 
                cube([Tray_Bottom_W,BoxSize_W,Tray_Bottom_T],false);
            //中
            for (i =[1:Tray_VS_Q-1])
            translate([(Keycaps_Space_L+Tray_Separator_T_W)*i-Tray_Separator_T_W+Tray_Fence_T,0,0])  
                cube([Tray_Separator_T_W,BoxSize_W,Tray_Bottom_T],false);
            }

        // 垂直分隔片  
        // 2、3 短隔板
        if(Tray_VS_Type==2 || Tray_VS_Type==3) {
              
            //上
            for (i =[1:Tray_VS_Q-1])
                for (j =[1:Tray_HS_Q])
            translate([(Keycaps_Space_L+Tray_Separator_T_W)*i+Tray_Fence_T-Tray_Separator_T_W,(Keycaps_Space_W+Tray_Separator_T_L)*j-Tray_Separator_L+Tray_Fence_T-Tray_Separator_T_L,0]) 
                cube([Tray_Separator_T_W,Tray_Separator_L,Tray_Separator_H_W+Tray_Bottom_T],false);
            //下
            for (i =[1:Tray_VS_Q-1])
                for (j =[1:Tray_HS_Q])
            translate([(Keycaps_Space_L+Tray_Separator_T_W)*i+Tray_Fence_T-Tray_Separator_T_W,(Keycaps_Space_W+Tray_Separator_T_L)*(j-1)+Tray_Fence_T,0]) 
                cube([Tray_Separator_T_W,Tray_Separator_L,Tray_Separator_H_W+Tray_Bottom_T],false);

            }
        // 2 全部
        else if(Tray_VS_Type==1) {
            //垂直分隔片    
            for (i =[1:Tray_VS_Q-1])
            translate([(Keycaps_Space_L+Tray_Separator_T_W)*i+Tray_Fence_T-Tray_Separator_T_W,0,0]) 
                cube([Tray_Separator_T_W,BoxSize_W,Tray_Separator_H_W+Tray_Bottom_T],false);
            
            }
         
        //多餘空間處理方式
        // 2 角落填補剩餘空間
         if (ExtraSpaceUse == 2) {
            //左下下
            translate([Tray_Fence_T2,-ES_W,0]) 
                cube([ES_WE,ES_W,ES_H],false);
            //左下左
             translate([-ES_L,Tray_Fence_T2,0]) 
                cube([ES_L,ES_LE,ES_H],false);    
             //左上左
             translate([-ES_L,BoxSize_W-ES_LE-Tray_Fence_T2,0]) 
                cube([ES_L,ES_LE,ES_H],false); 
             //左上上
             translate([Tray_Fence_T2,BoxSize_W,0]) 
                cube([ES_WE,ES_W,ES_H],false);
             //右下右
             translate([BoxSize_L,Tray_Fence_T2,0]) 
                cube([ES_L,ES_LE,ES_H],false);    
             //右下下
             translate([BoxSize_L-ES_WE-Tray_Fence_T2,-ES_W,0]) 
                cube([ES_WE,ES_W,ES_H],false);
             //右上右
             translate([BoxSize_L,BoxSize_W-ES_LE-Tray_Fence_T2,0]) 
                cube([ES_L,ES_LE,ES_H],false);    
             //右上上
             translate([BoxSize_L-ES_WE-Tray_Fence_T2,BoxSize_W,0]) 
                cube([ES_WE,ES_W,ES_H],false);
                
            }

         //Tray Fixed Slot Tenon (in Corner )
         //托盤固定槽榫（位於角落）
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

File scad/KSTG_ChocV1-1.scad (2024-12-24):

// 鍵帽儲存托盤產生器
// Keycap Storage Tray Generator
include <KSTG_Base.SCAD>

// 可複製此樣板檔依照自己需求另存新檔
// 以便以檔案區隔樣式

// 存放盒子的大小:
//BoxSize_L1 = 190; //長度(水平)
//BoxSize_W1 = 120; //寬度(垂直)
//BoxSize_H1 = 55;  //高度


//A4紙的尺寸是210mm×297mm
//BoxSize_L1 = 297/2; //長度(水平)
//BoxSize_L1 = 297/15*7-5; //長度(水平)
//BoxSize_L1 = 297/15*8; //長度(水平)

//BoxSize_W1 = 210/2; //寬度(垂直)
//BoxSize_W1 = 210/11*5+1; //寬度(垂直)
//BoxSize_W1 = 210/11*6+1; //寬度(垂直)

//BoxSize_L1 = 308/16*9+0; //長度(水平)
//BoxSize_W1 = 223/11*5+0; //寬度(垂直)

BoxSize_L1 = 308/16*9+0; //長度(水平)
BoxSize_W1 = 223/11*5+0; //寬度(垂直)

BoxSize_H1 = 55;  //高度


// 外圍
Tray_Fence_T = 2;  //厚度
Tray_Fence_H = 4;  //高度

//放置鍵帽空間
Keycaps_Space_L = 17.6;
Keycaps_Space_W = 16.6;

// 分隔片
//Tray_Separator_T = 0.8;  //厚度
Tray_Separator_H = 4;  //高度 建議高於上一層與此層鍵帽間的空隙,避免運輸時鍵帽脫落跑到其他空間
Tray_Separator_L = 3;  //短隔板長度
Tray_Separator_T_L = 1.5;  //厚度 (長;水平) 
Tray_Separator_T_W = 0.5;  //厚度 (寬;垂直)

// 分隔片(長寬區分/尚未使用)
//Tray_Separator_H_L = 5;  //長(水平) 高度
//Tray_Separator_H_W = 5;  //寬(垂直) 高度

// 底板 分隔板往中心延伸的底板
Tray_Bottom_L = (Keycaps_Space_W-9)/2; //水平底板寬度
Tray_Bottom_W = (Keycaps_Space_L-14)/2; //垂直底板寬度
Tray_Bottom_T = 2; //底板厚度

//常見鍵帽高度表:
//SA  16.5mm  Cherry 9.4mm
//OEM 11.9mm  TAI HAO 14.8
//XDA 9.1mm   DSA 7.6
//ADA 8mm (18.2x18.2mm )
//適用於 Tray_Column_H 參數

//四角落立柱高度
//堆疊托盤時可墊高避免直接碰觸鍵帽
Tray_Column_H = 4; // 高度 可依照鍵帽高度調整
Tray_Column_T = 2;  // 厚度
Tray_Column_L = 30; // 長面長度
Tray_Column_W = 30; // 寬面長度 

//垂直分隔片樣式
// 0 不需要
// 1 全部
// 2 短隔板無垂直底板
// 3 短隔板有垂直底板
// 4 無隔板有垂直底板

Tray_VS_Type = 4;

//多餘空間處理方式
//How to use the extra space
// 0 不處理，照原本盒子大小產生外圍
// 1 不處理，僅列印鍵帽所需空間
// 2 角落填補剩餘空間
ExtraSpaceUse = 2;

//填補空間高度
ES_H = Tray_Column_H + Tray_Column_T; 
//ES_H = Tray_Separator_H + Tray_Separator_T;

//是否顯示文字標記 0關/1開
ShowText = 1 ;

//請參考F5後帶出的座標數值
//例如：
// Tray_Separator_Cut_L=[
// [1,1],[2,1],[3,1],[1,2]
// ];

//清除分隔片與底板

// 長(水平)分隔片 紅色
Tray_Separator_Cut_L=[
//[4,1],[4,3]
];
// 寬(垂直)分隔片 藍色 -vnm,     
Tray_Separator_Cut_W=[
//[1,1]
];
// 交錯點 綠色 長寬分隔片交會處
// 須手動清除交錯點
Tray_Separator_Cut_C=[
];
// 長(水平)底板 紅色
Tray_Separator_Cut_LB=[
//[4,1],[4,3]
];
// 寬(垂直)底板 藍色
Tray_Separator_Cut_WB=[
//[1,1]
];

//增加分隔片與底板

// 長(水平)分隔片 紅色
Tray_Separator_Put_L=[
];
// 寬(垂直)分隔片 藍色     
Tray_Separator_Put_W=[
];
// 交錯點 綠色 長寬分隔片交會處
// 須手動清除交錯點
Tray_Separator_Put_C=[
];
// 長(水平)底板 紅色
Tray_Separator_Put_LB=[
//[4,1],[4,3]
];
// 寬(垂直)底板 藍色
Tray_Separator_Put_WB=[
];

CreateKST();

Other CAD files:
scad/KSTG_ChocV1-2.scad
scad/KSTG_ChocV1-3.scad
scad/KSTG_Template.scad
stl_Sample/KSTG_Sample1.scad
stl_Sample/KSTG_Sample2.scad
stl_Sample/KSTG_Sample3.scad
stl_Sample/KSTG_Sample4.scad
stl_Sample/KSTG_Sample5.scad
stl_Sample/KSTG_Sample6.scad
stl_Sample/KSTG_Sample7.scad

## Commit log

2022-02-06 Update KSTG_Base.SCAD
    fix corner issue
    [KSTG_Base.SCAD]
2022-06-27 Update KSTG_Base.SCAD
    增加 多餘空間H(頂層) 的資訊
    [KSTG_Base.SCAD]
2022-06-27 Update KSTG_Template.scad
    依照Base變動, BoxSize_H 改成 BoxSize_H1
    [KSTG_Template.scad]
2024-12-15 功能補強
    加上底板與分隔板增加的功能與參數
    可製作自定義的間隔區間
    加上填補空間高度的參數，填補間隔的部分可以自定義高度
    垂直底板的設定，增加「4 無隔板有底板」
    [KSTG_Base.SCAD, KSTG_Template.scad]
2024-12-24 增加參數
    Tray_Separator_T_L = 1; //厚度(長;水平)
    Tray_Separator_T_W = 2; //厚度(寬;垂直)
    Tray_Bottom_W = (Keycaps_Space_L-12)/2; //垂直底板寬度
    垂直分隔片樣式 新增
    4 無隔板有垂直底板
    //填補空間高度
    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
    [KSTG_Base.SCAD, KSTG_ChocV1-1.scad, KSTG_ChocV1-2.scad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]
2025-05-08 新增功能照片
2025-05-08 Update README.md
    更新說明
2025-05-08 新增Choc V1 stem socket以及許多新參數
    [KSTG_Base.SCAD, KSTG_Template.scad]
2025-05-08 更新參數說明
    [design.xls]
2025-08-02 Update KSTG_Base.SCAD
    新增 "Choc_Base2" 的 BlockPutObj_Name 類型
    [KSTG_Base.SCAD]
